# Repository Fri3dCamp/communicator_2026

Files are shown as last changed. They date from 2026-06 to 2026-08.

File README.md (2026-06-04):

# Communicator 2026
In deze Git repository kan je de ontwerpbestanden en productiedata vinden van de [Fri3d Camp](https://fri3d.be/) 2026 communcator add-on. Revisie 01 is de versie die je in de zakjes kan terugvinden.

De PCB bevat volgende elementen:

- [WCH CH32X035](https://www.wch-ic.com/products/CH32X035.html) microcontroller voor het keyboard
- [I²S Microfoon](datasheets/MIC.pdf)
- [I²S DAC met versterker](datasheets/AMP.pdf)

In de zak zal je ook nog volgende items aantreffen:

- [Luidspreker](Datasheets/SPK.pdf)
- 2 lange pin headers
- Cover PCB
- 4 lange plastieken spacers
- 4 korte plastieken spacers

Je zal zelf de speaker en pin headers nog moeten solderen, het siliconen keyboard op de PCB monteren met de afdekplaat en het op de badge klikken.

Het keyboard werkt ook als USB keyboard.

[//]: # (Communicator 2026)

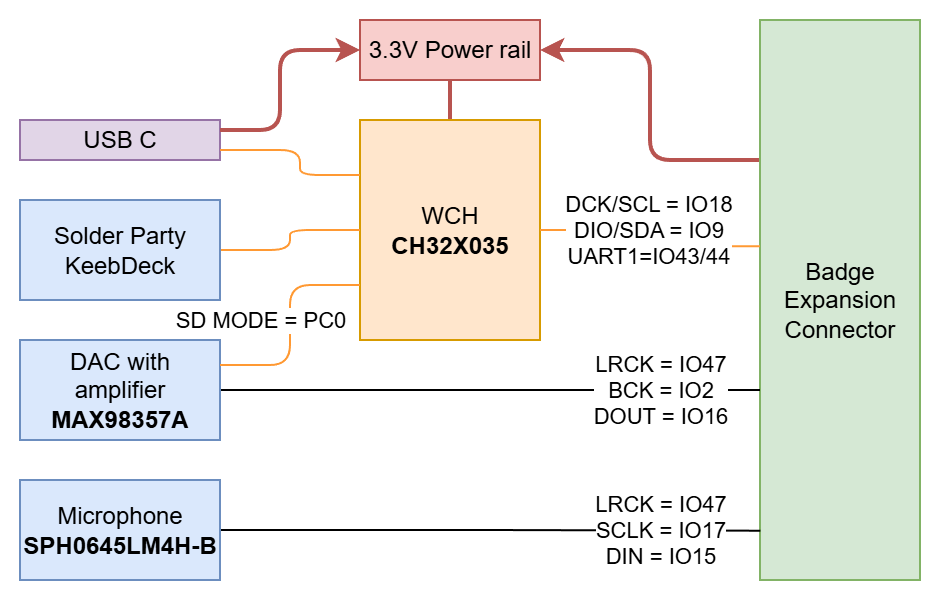
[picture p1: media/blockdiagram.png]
Communicator 2026 blockdiagram


# Communicator 2026 (EN)
Communicator addon for the Fri3d Badge based on the [Solder Party KeebDeck Keyboard](https://www.solder.party/keeb/). The design is very similar to the [previous generation](https://github.com/Fri3dCamp/communicator_2024) but we ditched the [LANA TNY](https://phyx.be/LANA_TNY/) module in favor of the [WCH CH32X035](https://www.wch-ic.com/products/CH32X035.html) microcontroller.

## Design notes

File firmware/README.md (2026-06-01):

## Fri3d Camp 2026 Communicator add-on firmware

This firmware runs on the Fri3d camp 2026 communicator add-on board, which is powered by [CH32X035](https://www.wch-ic.com/products/CH32X035.html) MCU, the same part that can be found as a coprocessor on the Fri3d badge 2026. More information about the 2026 communicator addon can be found [here](https://fri3dcamp.github.io/badge_2026/en/communicator/) ([dutch](https://fri3dcamp.github.io/badge_2026/communicator)). This MCU only controls the keyboard part of the communicator. The audio related functions of the communicator are handled by the main MCU of Fri3d badge through the expansion connector.

The firmware outputs [HID report packets](https://files.microscan.com/helpfiles/ms4_help_file/ms-4_help-02-46.html) (8 bytes) on USB and UART on the expansion connector. So the 2026 communicator addon can be used standalone using the USB connector attached to a PC for use as a normal keyboard, or in combination with the Fri3d badge [2024](https://github.com/Fri3dCamp/badge_2024) or [2026](https://github.com/Fri3dCamp/badge_2026) using the expansion connector.

## HID Report packets

A HID report packet ([Protocol 1](https://www.usb.org/sites/default/files/hid1_11.pdf)) consists of 8 bytes. The first byte indicates the modifier keys that have been pressed:

| Bit | Modifier Key |
|-|-|
| 7 | RIGHT GUI |
| 6 | RIGHT ALT |
| 5 | RIGHT SHIFT |
| 4 | RIGHT CTRL |
| 3 | LEFT GUI |
| 2 | LEFT ALT |
| 1 | LEFT SHIFT |
| 0 | LEFT CTRL |

The second byte is reserved, the remaining 6 bytes can contain a [HID keycode](https://gist.github.com/MightyPork/6da26e382a7ad91b5496ee55fdc73db2).

On the 2026 communicator, UART RX is also connected to the expansion connector. This means the badge firmware can send a byte to control the backlight of the 2026 communicator. The byte should set a value between 0 and 100.

### I2C

The Fri3d badge [2024](https://github.com/Fri3dCamp/badge_2024) and [2026](https://github.com/Fri3dCamp/badge_2026) can also communicate with the 2026 communicator add-on through I2C (address ```0x40```). The following registers can be used to interface/control with the add-on:

| Register | Name | Access | Bytes | description |
|-|-|-|-|-|
| 0x00 | Version number | R | 3 | Reports the firmware version number |
| 0x03 | current HID report packet | R | 8 | An 8-byte HID report packet (see above) |
| 0x0b | Configuration | R/W | 1 | a 1-byte configuration register (see below) |
| 0x0c | Backlight | R/W | 2 | Keyboard backlight intensity (0-100) |

The configuration is a 1-byte value with the following encoding:
| Bit | Name |
|-|-|
| \[7:2\] | reserved |
| 1 | reboot to bootloader |
| 0 | enable interrupt mode (not implemented yet) |

## Building

Use [platformio](https://platformio.org) to build this project. You should install the [ch32v platform package](https://github.com/Community-PIO-CH32V/platform-ch32v) as well. If you use the command line, build using:

```
pio run
```

## Flashing

### Through USB

To flash your device, unplug the USB cable, press and hold the boot button on the board while plugging in the USB cable again. Then upload using the command:

```
pio run -t upload
```

It will use [wchisp](https://github.com/Community-PIO-CH32V/tool-wchisp) to flash the binary to the [CH32X035](https://www.wch-ic.com/products/CH32X035.html) chip.

### Using your badge

Unlike the 2024 communicator, the 2026 communicator can be reflashed by your badge.
TODO: link to flashing instructions (micropython app?)

## Usage

The keyboard presents itself as a HID input device.
The ```Fn``` key can be used to trigger special functions:
 * ```Fn+Backspace```: Delete
 * ```Fn+Up```: Page Up
 * ```Fn+Down```: Page Down
 * ```Fn+Left```: Home
 * ```Fn+Right```: End
 * ```Fn+Spacebar```: Toggle keyboard backlight
 * ```Fn+Right Shift```: Toggle Caps Lock

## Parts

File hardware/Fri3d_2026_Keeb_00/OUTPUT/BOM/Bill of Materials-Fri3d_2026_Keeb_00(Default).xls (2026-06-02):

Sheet: BOM Report
Bill of Materials |  |  | Fri3D 2026 Keeb
Project: |  | Fri3d_2026_Keeb_00.PrjPcb
Revision: |  | 00
Variant: |  | Default
Creation Date: | 01/03/2026 | 23:25
Print Date: | 2026-03-18 | 19:16:56
Footprint | Comment | LibRef | Designator | Value | Description | Supplier 1 | Supplier Part Number 1 | Supplier 2 | Supplier Part Number 2 | Supplier 3 | Supplier Part Number 3 | Quantity
C0805_N |  | CAP # 10uF 10V 0805 | C1 | 10uF 10V | CAP # 10uF 10V 0805 | Farnell | 2320859 | LCSC | C17024 | Generic | 10uF 10V 0805 X7R | 1
C0603_N |  | CAP # 100nF 16V 0603 | C2, C8, C9 | 100nF 16V | CAP # 100nF 16V 0603 | LCSC | C282519 |  |  | Generic | 100nF 16V 0603 X7R | 3
C0603_N |  | CAP # 220pF 50V 0603 | C3, C4 | 220pF | CAP # 220pF 50V 0603 | LCSC | C5254623 | LCSC | C107081 | Generic | 220pF 0603 | 2
C0603_N |  | CAP # 1uF 50V 0603 | C5, C6 | 1uF 50V | CAP # 1uF 50V 0603 | Farnell | 2112858 |  |  | Generic | 1uF 50V 0603 X7R | 2
LITE_LTW-010DCG | Side emitting Cool White LED 3.0V 30mA 120° 2900mcd | LED # White Side Emitting LTW-010DCG-SR-G | D1, D2, D3, D4, D5, D6, D7, D8 | LTW-010DCG-SR-G | LED # White Side Emitting LTW-010DCG-SR-G | LCSC | C5175311 | LCSC | C5175309 | LCSC | C5175310 | 8
SOD-323_AC | CUS10S30 Schottky Power Rectifier, 1A, 30V | Schottky # CUS10S30 | D9 | CUS10S30,H3F | Schottky # CUS10S30 | LCSC | C146335 |  |  |  |  | 1
L0603 | BLM18KG601SN1D | FER # 600R 1A3 0603 0R15 BLM18KG601SN1D | F1, F2 | 1A3 0R15 | FER # 600R 1A3 0603 0R15 BLM18KG601SN1D | Farnell | 1781094 | LCSC | C85833 |  |  | 2
XUNPU-TYPEC-304S-ACP16 | USB 2.0 C Reversible Receptacle Horizontal full SMD | USB # C 2.0 RCPT TYPEC-304S-ACP16 | J1 | TYPEC-304S-ACP16 | USB # C 2.0 RCPT TYPEC-304S-ACP16 | LCSC | C5187472 | LCSC | C2927040 | LCSC | C5156603 | 1
HDR2X6 | Header 6X2 | Pin Header 2.54mm dual row 12way | P1 |  | Pin Header 2.54mm dual row 12way |  |  |  |  |  |  | 1
R0603_N |  | RES # 100R 0603 | R1, R5, R12, R13, R14, R15, R16, R17 | 100R | RES # 100R 0603 | Farnell | 2446544 | LCSC | C22775 | Generic | 100R 1% 0603 | 8
R0603_N |  | RES # 100K 0603 | R3, R6, R7, R18 | 100K | RES # 100K 0603 | LCSC | C25803 | LCSC | C14675 | Generic | 100K 1% 0603 | 4
R0603_N |  | RES # 1M 0603 | R4 | 1M | RES # 1M 0603 | LCSC | C22935 | LCSC | C105578 | Generic | 1M 1% 0603 | 1
R0603_N |  | RES # 5K1 0603 | R10, R11 | 5K1 | RES # 5K1 0603 | Farnell | 2845922 | LCSC | C112314 | Generic | 5K1 1% 0603 | 2
 | INGHAi GSPK3020035PN 8R 1W 100mm Leads | SPEAKER 8R 1W 10cm | SPK1 | GSPK3020035PN-8R1.0W-L100 | SPEAKER 8R 1W 10cm | LCSC | C530556 |  |  |  |  | 1
Solder_Party_Keyb | Full QWERTY Keyboard Solder Party Dome Sheet | Solder_Party_Keyb | SW1 |  |  |  |  |  |  |  |  | 1
WE_430181038816 | 4.5x4.5mm tact SMD H3,8mm | SW # TACT small 4.5x4.5mm SMD WS-TASV | SW2 | 430181038816 | SW # TACT small 4.5x4.5mm SMD WS-TASV | Wurth | 430181038816 | Mouser | 710-430181038816 | LCSC | C174049 | 1
SOT23-3 | 0.2A N-Ch MOSFET Vgs 1.5 | BSS138 N-Ch MOSFET 0.2A 1.5Vgs 60Vds | T1 | BSS138 | BSS138 N-Ch MOSFET 0.2A 1.5Vgs 60Vds | Farnell | 2432717 | LCSC | C426569 | LCSC | C5224260 / C5224267 | 1
QFN_16_0.5_3X3 | Mono I²S DAC AMP 3W 2.5~5.5V | AMP # AUD MAX98357A | U1 | MAX98357A | AMP # AUD MAX98357A | Farnell | 2949165 | LCSC | C910544 |  |  | 1
SOT23-5 | 3V3 LDO 300mA 150mV | LDO # 3V3 300mA RT9078-33GJ5 | U2 | RT9078-33GJ5 | LDO # 3V3 300mA RT9078-33GJ5 | LCSC | C110427 |  |  |  |  | 1
TDK_ICS-43434 | I2S MIC ICS-43434 | MIC # MEMS I2S ICS-43434 | U5 | ICS-43434 | MIC # MEMS I2S ICS-43434 | Mouser | 410-ICS-43434 | Farnell | 2911502 |  |  | 1
QFN_28_4.0x4.0_P0.4 | WCH CH32X035G8U6 QFN28 RISC-V 32-bit MCU, 62KB Flash, 10KB RAM, USB PD | RISCV # CH32X035G8U6 | U6 | CH32X035G8U6 | RISCV # CH32X035G8U6 | LCSC | C7437027 |  |  |  |  | 1
 |  |  |  |  |  |  |  |  |  |  |  | 44
Approved |  | Notes

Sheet: Print
Footprint | Designator | Description | Quantity
C0805_N | C1 | CAP # 10uF 10V 0805 | 1
C0603_N | C2, C8, C9 | CAP # 100nF 16V 0603 | 3
C0603_N | C3, C4 | CAP # 220pF 50V 0603 | 2
C0603_N | C5, C6 | CAP # 1uF 50V 0603 | 2
LITE_LTW-010DCG | D1, D2, D3, D4, D5, D6, D7, D8 | LED # White Side Emitting LTW-010DCG-SR-G | 8
SOD-323_AC | D9 | Schottky # CUS10S30 | 1
L0603 | F1, F2 | FER # 600R 1A3 0603 0R15 BLM18KG601SN1D | 2
XUNPU-TYPEC-304S-ACP16 | J1 | USB # C 2.0 RCPT TYPEC-304S-ACP16 | 1
HDR2X6 | P1 | Pin Header 2.54mm dual row 12way | 1
R0603_N | R1, R5, R12, R13, R14, R15, R16, R17 | RES # 100R 0603 | 8
R0603_N | R3, R6, R7, R18 | RES # 100K 0603 | 4
R0603_N | R4 | RES # 1M 0603 | 1
R0603_N | R10, R11 | RES # 5K1 0603 | 2
Solder_Party_Keyb | SW1 |  | 1
WE_430181038816 | SW2 | SW # TACT small 4.5x4.5mm SMD WS-TASV | 1
SOT23-3 | T1 | BSS138 N-Ch MOSFET 0.2A 1.5Vgs 60Vds | 1
QFN_16_0.5_3X3 | U1 | AMP # AUD MAX98357A | 1
SOT23-5 | U2 | LDO # 3V3 300mA RT9078-33GJ5 | 1
TDK_ICS-43434 | U5 | MIC # MEMS I2S ICS-43434 | 1
QFN_28_4.0x4.0_P0.4 | U6 | RISCV # CH32X035G8U6 | 1
 |  |  | 43
Approved

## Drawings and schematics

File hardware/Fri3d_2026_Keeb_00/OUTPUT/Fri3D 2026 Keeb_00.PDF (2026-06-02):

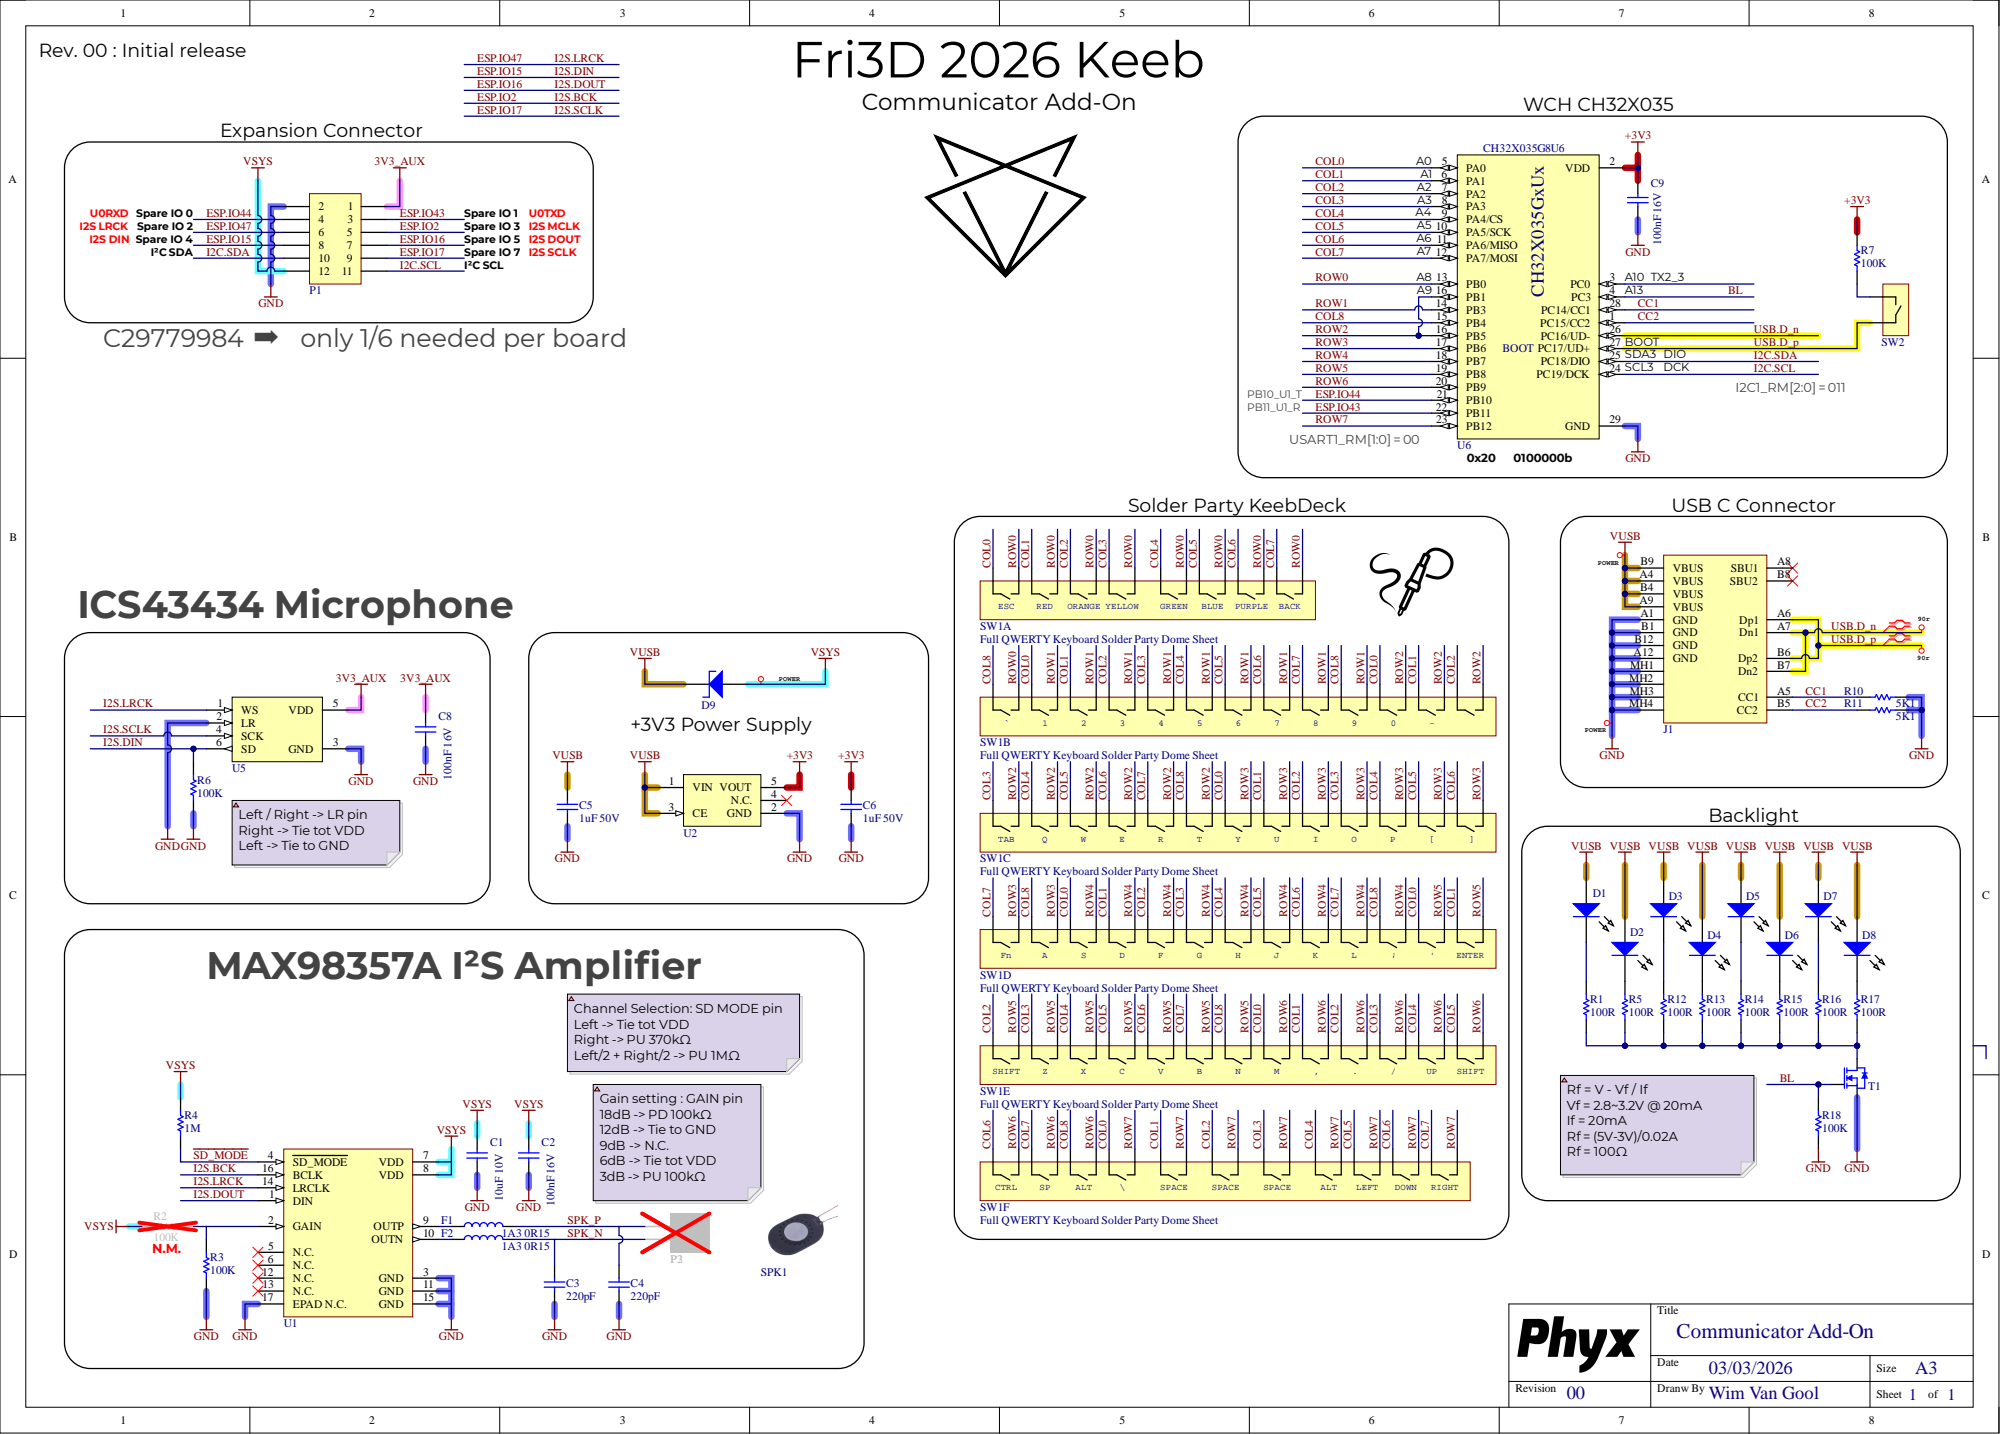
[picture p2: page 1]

Fri3D 2026 Keeb Rev. 00 : Initial release

C29779984 ➡ only 1/6 needed per board

Full QWERTY Keyboard Solder Party Dome Sheet

GND A12
MH1

MH2
MH3

Left / Right -> LR pin
Right -> Tie tot VDD
Left -> Tie to GND

VUSB VUSB VUSB VUSB VUSB VUSB VUSB

Channel Selection: SD MODE pin
Left -> Tie tot VDD
Right -> PU 370kΩ
Left/2 + Right/2 -> PU 1MΩ

Gain setting : GAIN pin
12dB -> Tie to GND

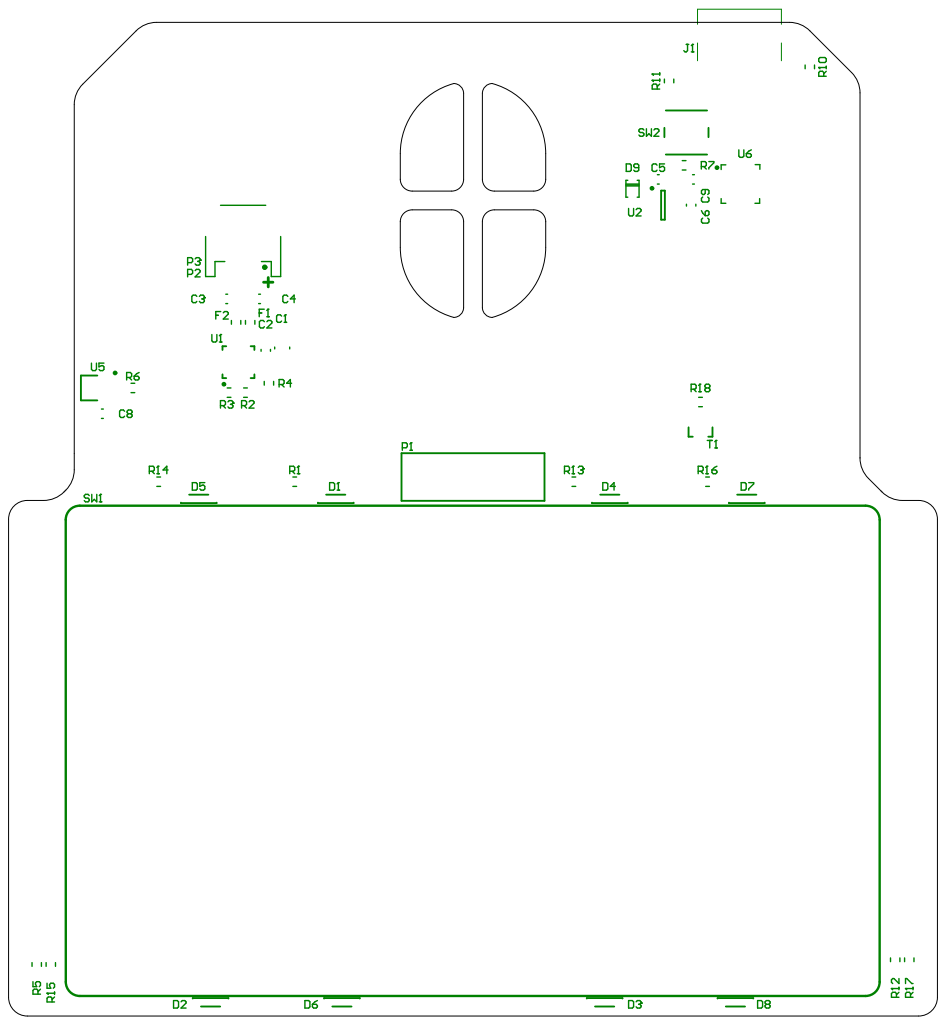
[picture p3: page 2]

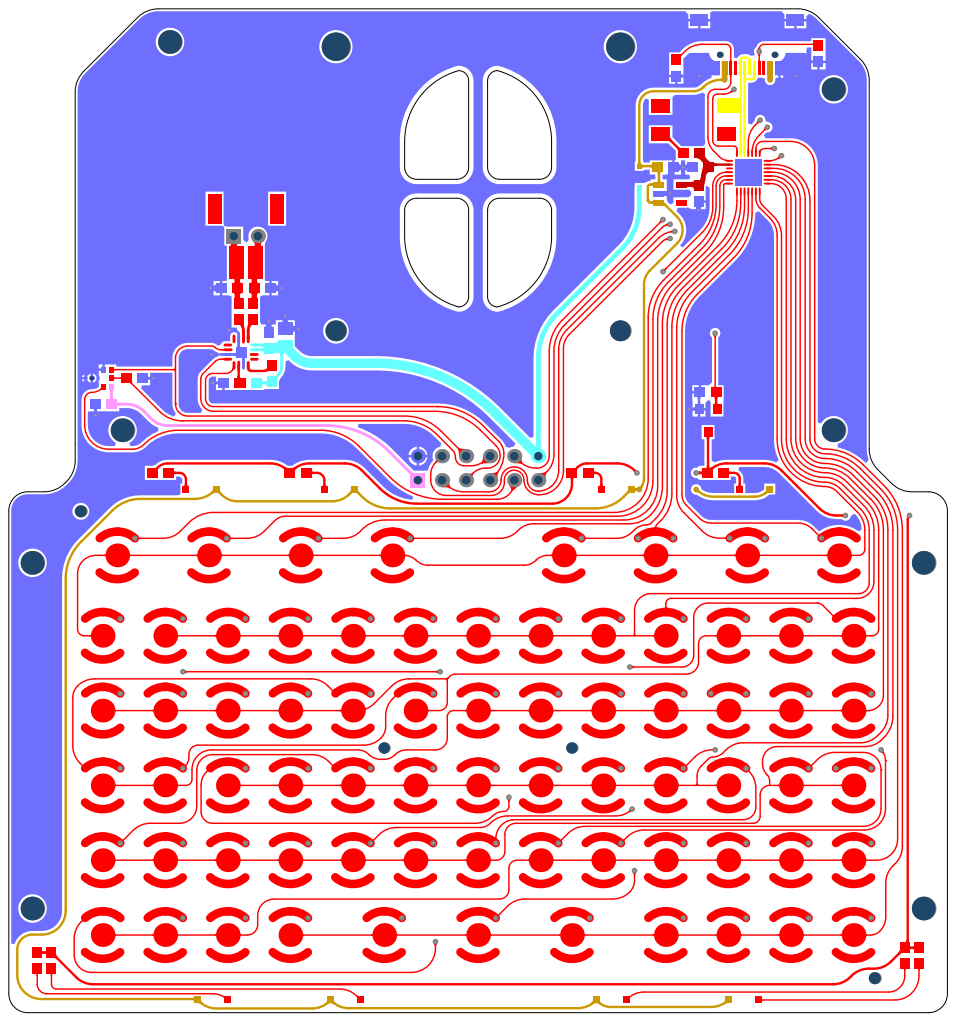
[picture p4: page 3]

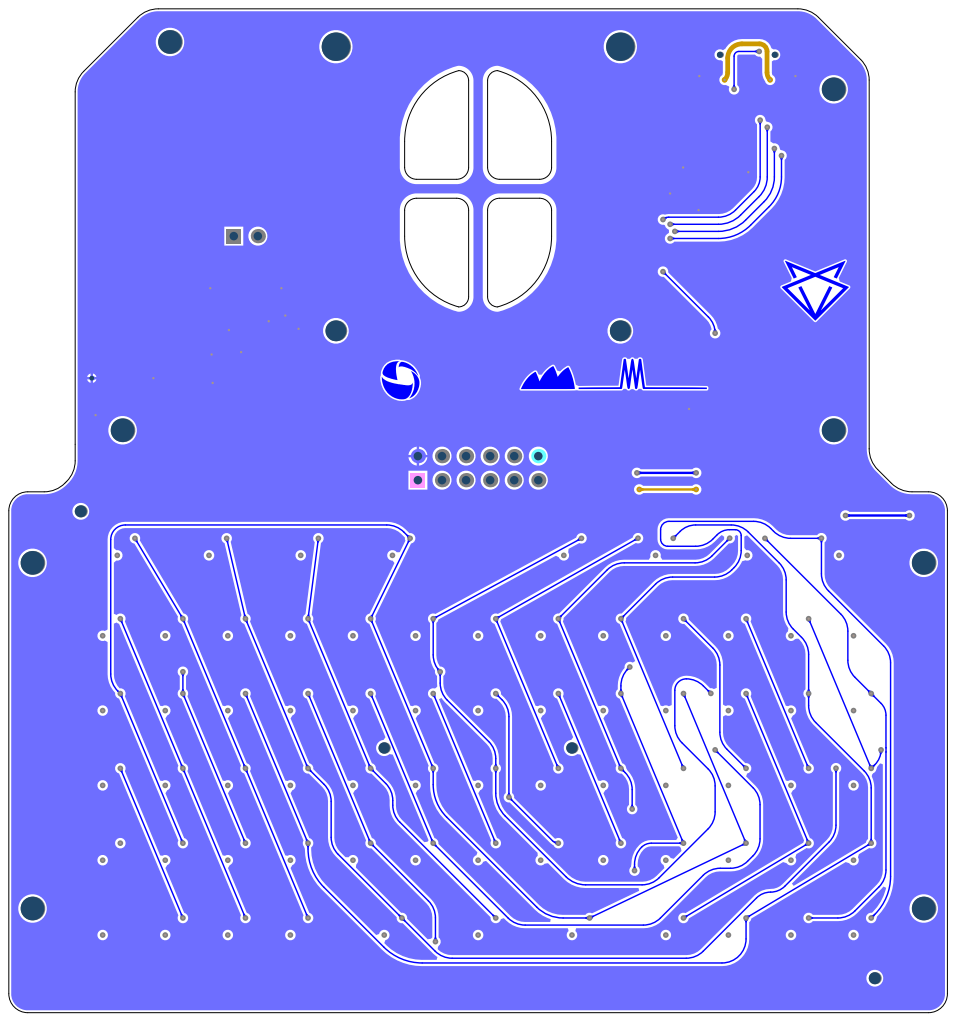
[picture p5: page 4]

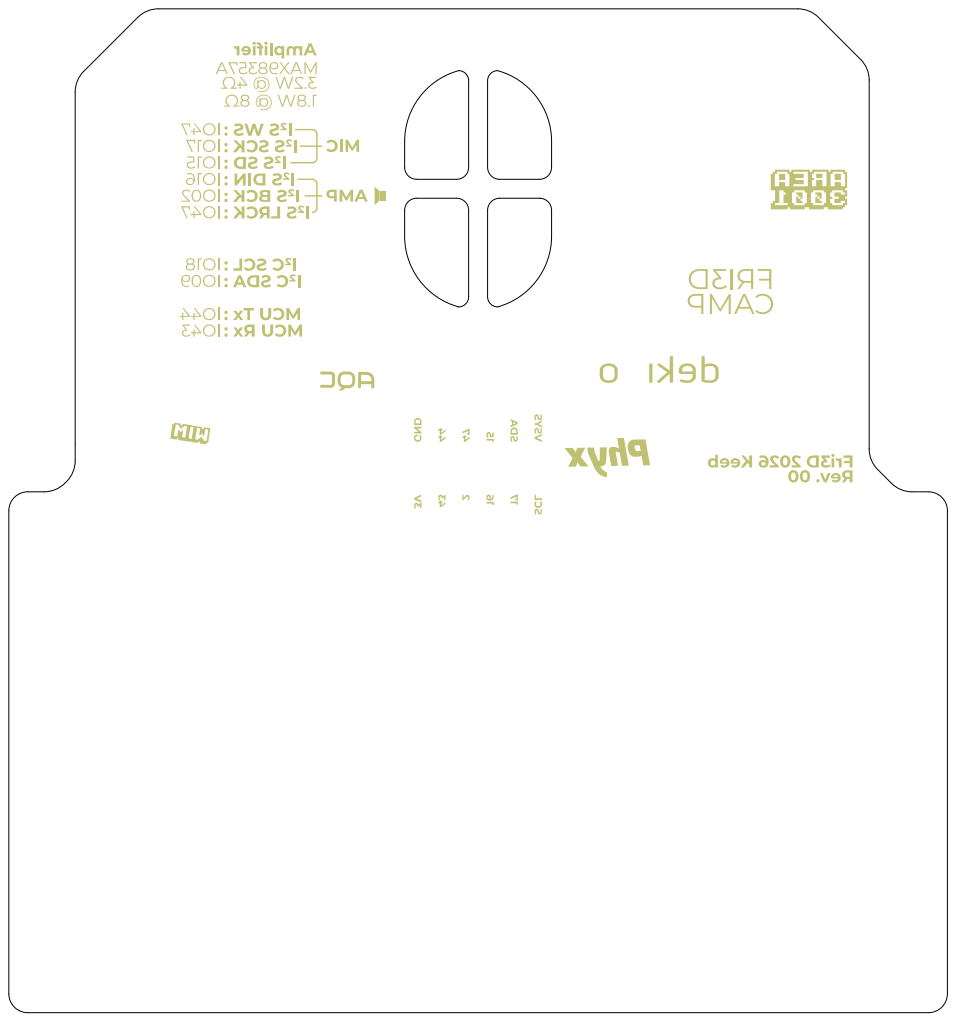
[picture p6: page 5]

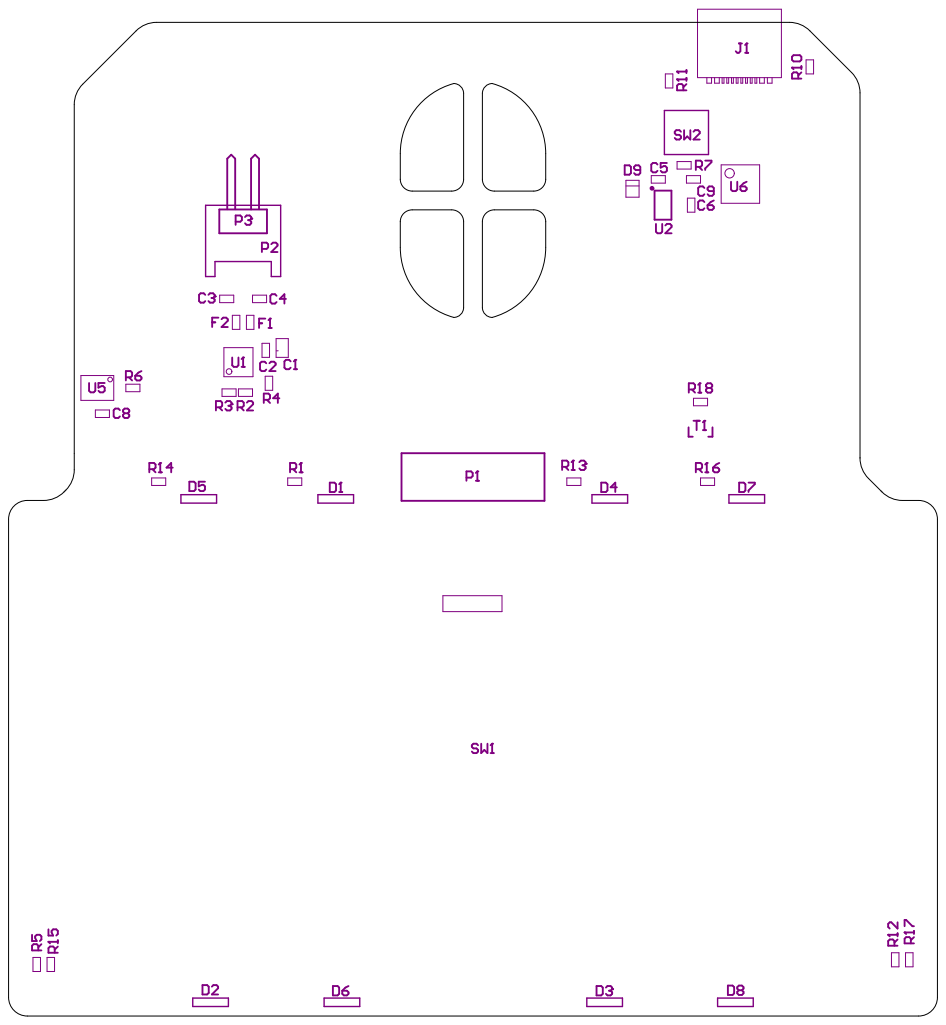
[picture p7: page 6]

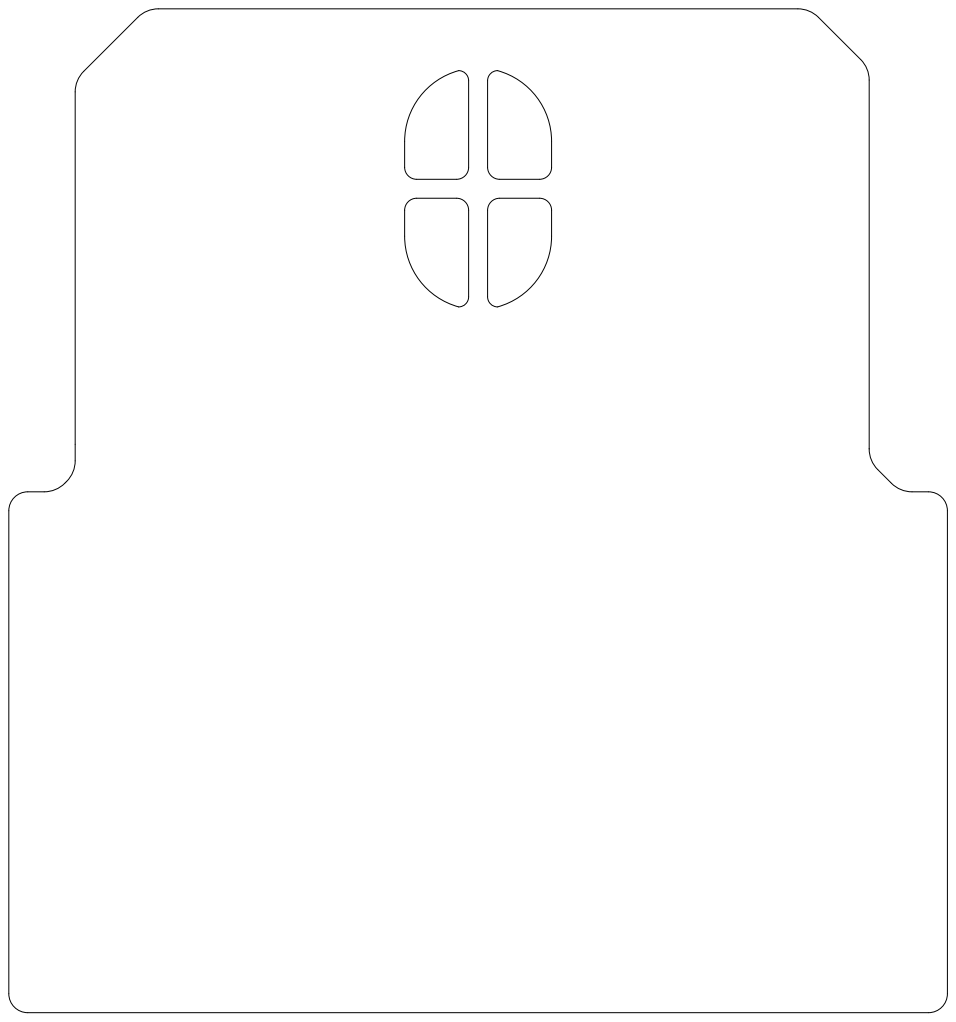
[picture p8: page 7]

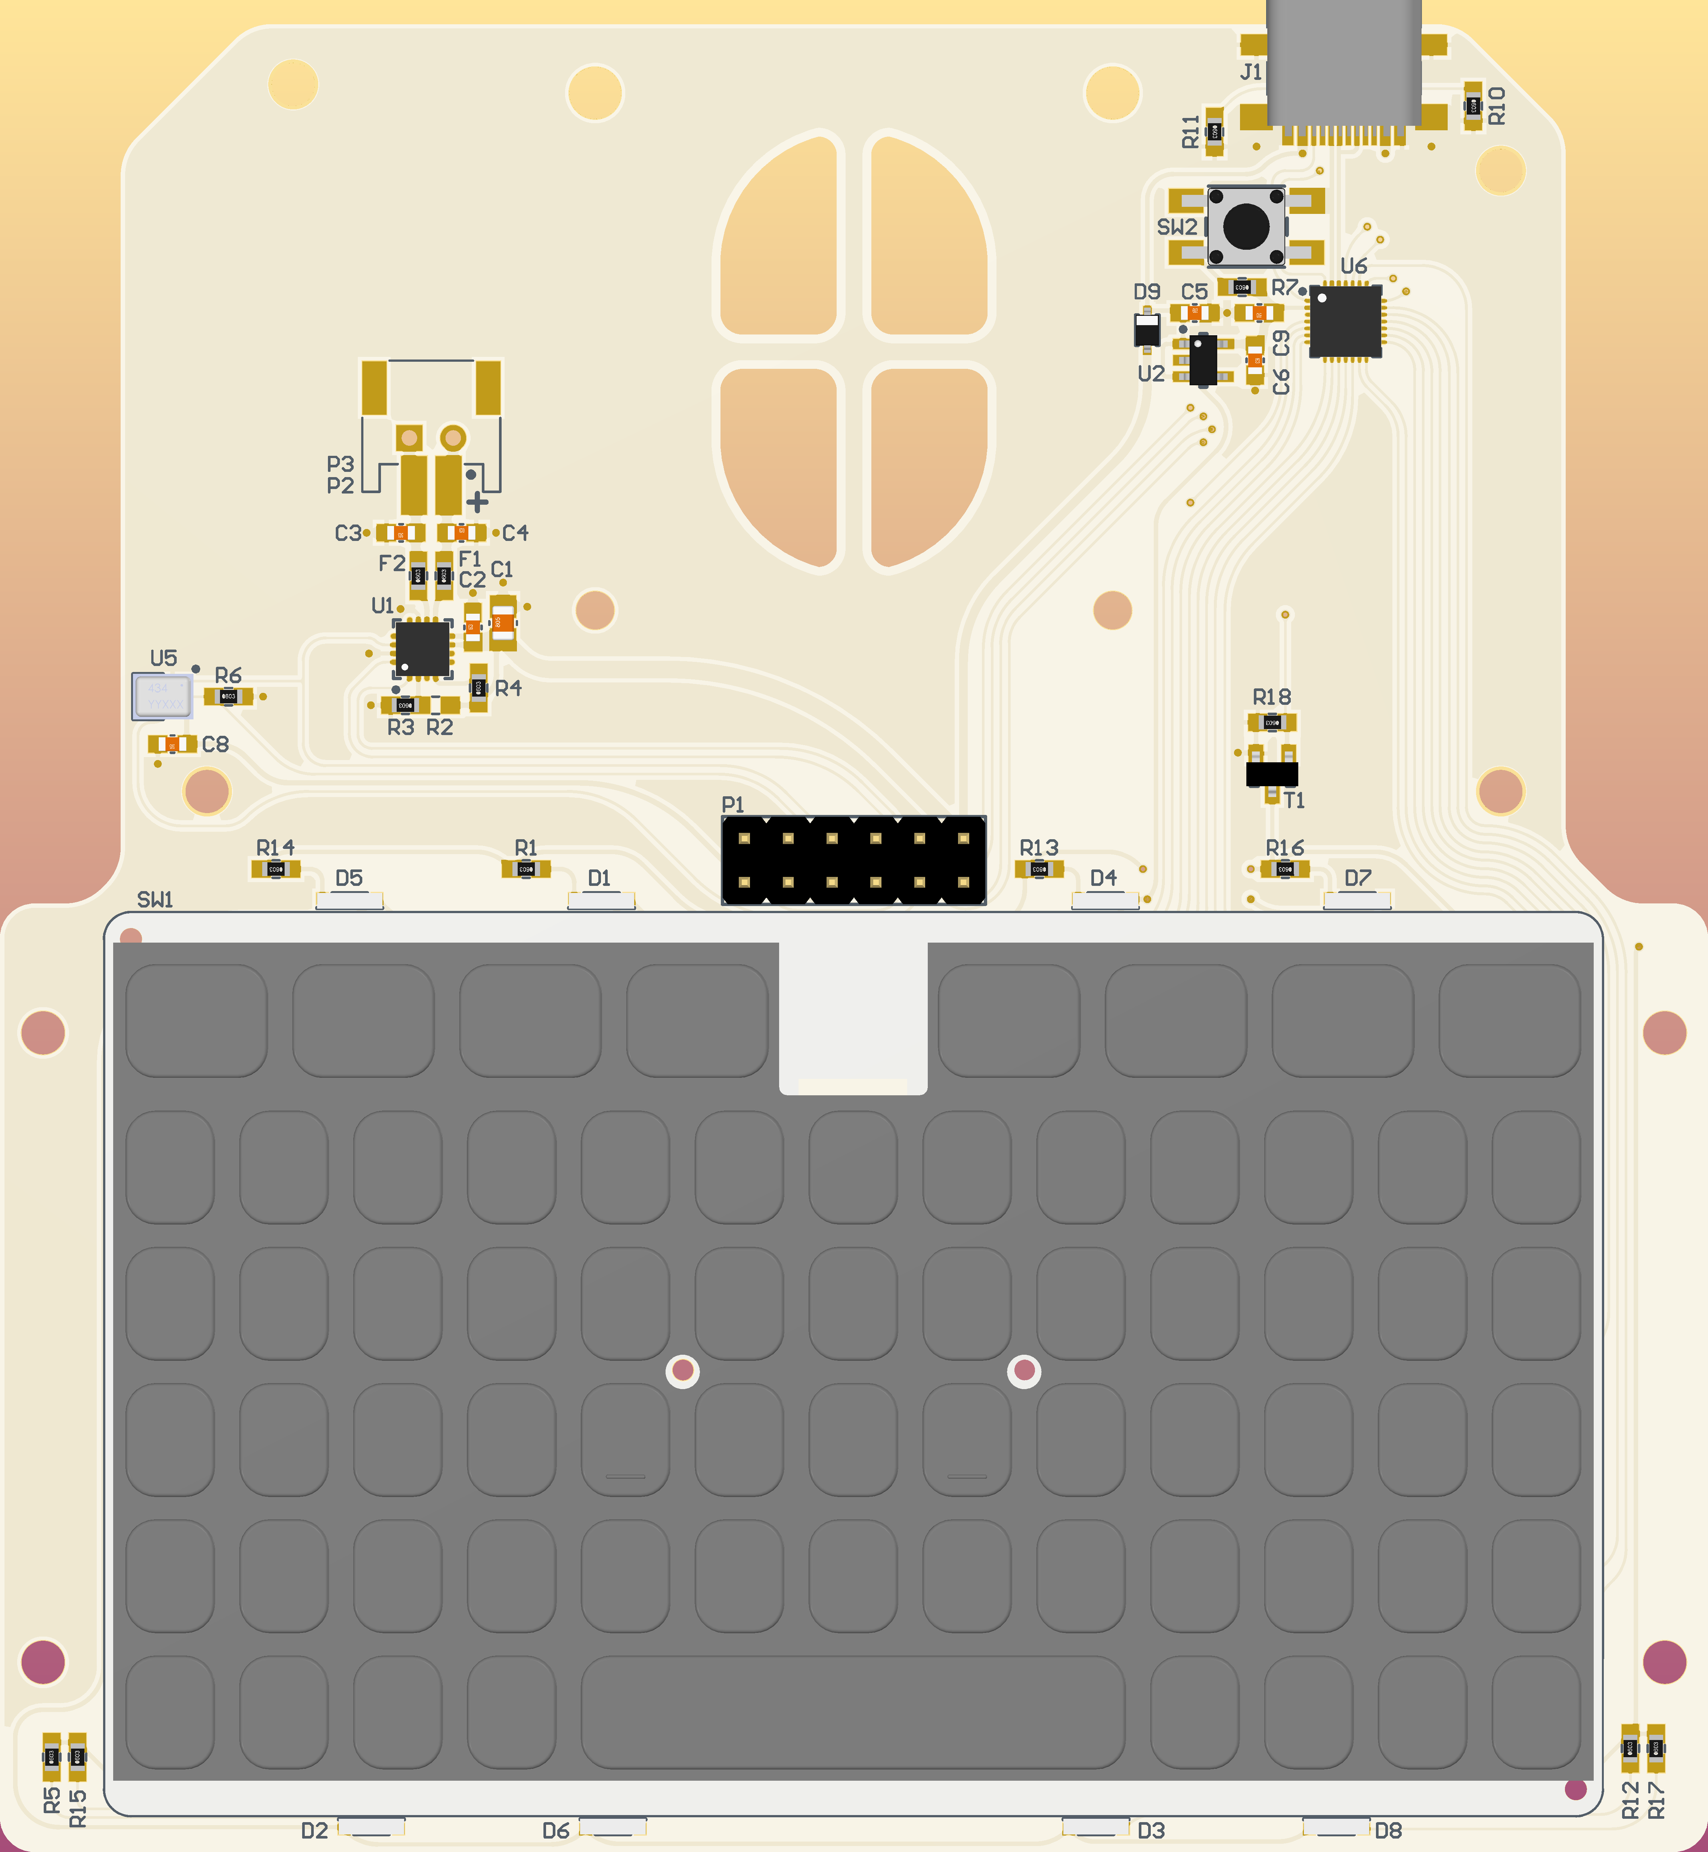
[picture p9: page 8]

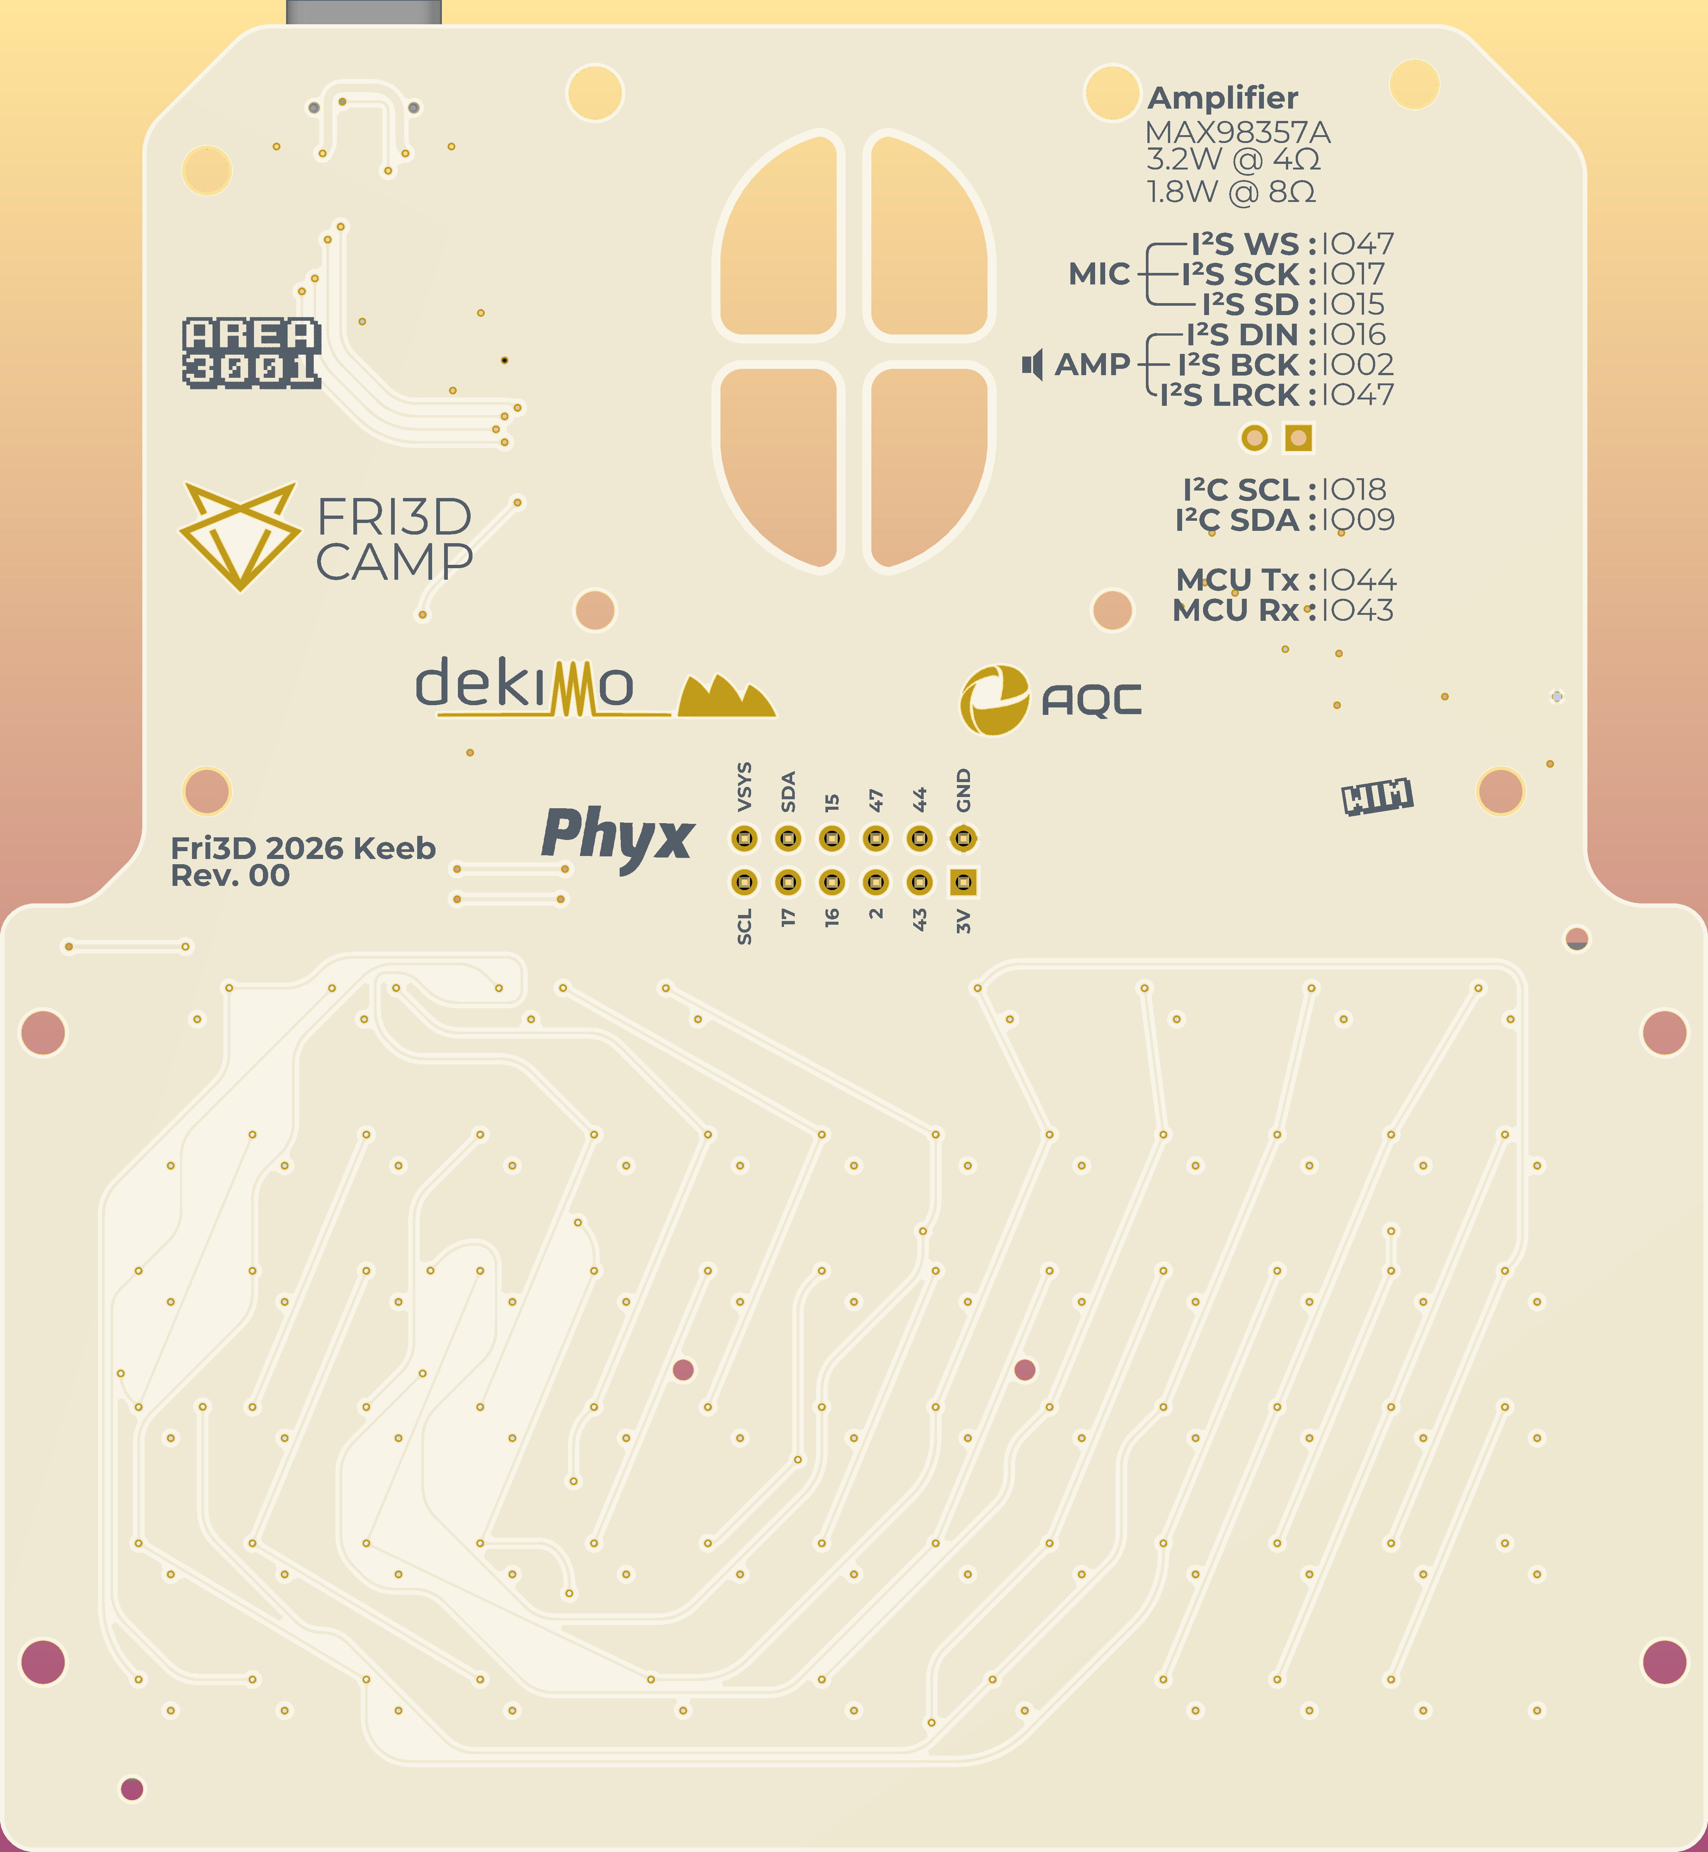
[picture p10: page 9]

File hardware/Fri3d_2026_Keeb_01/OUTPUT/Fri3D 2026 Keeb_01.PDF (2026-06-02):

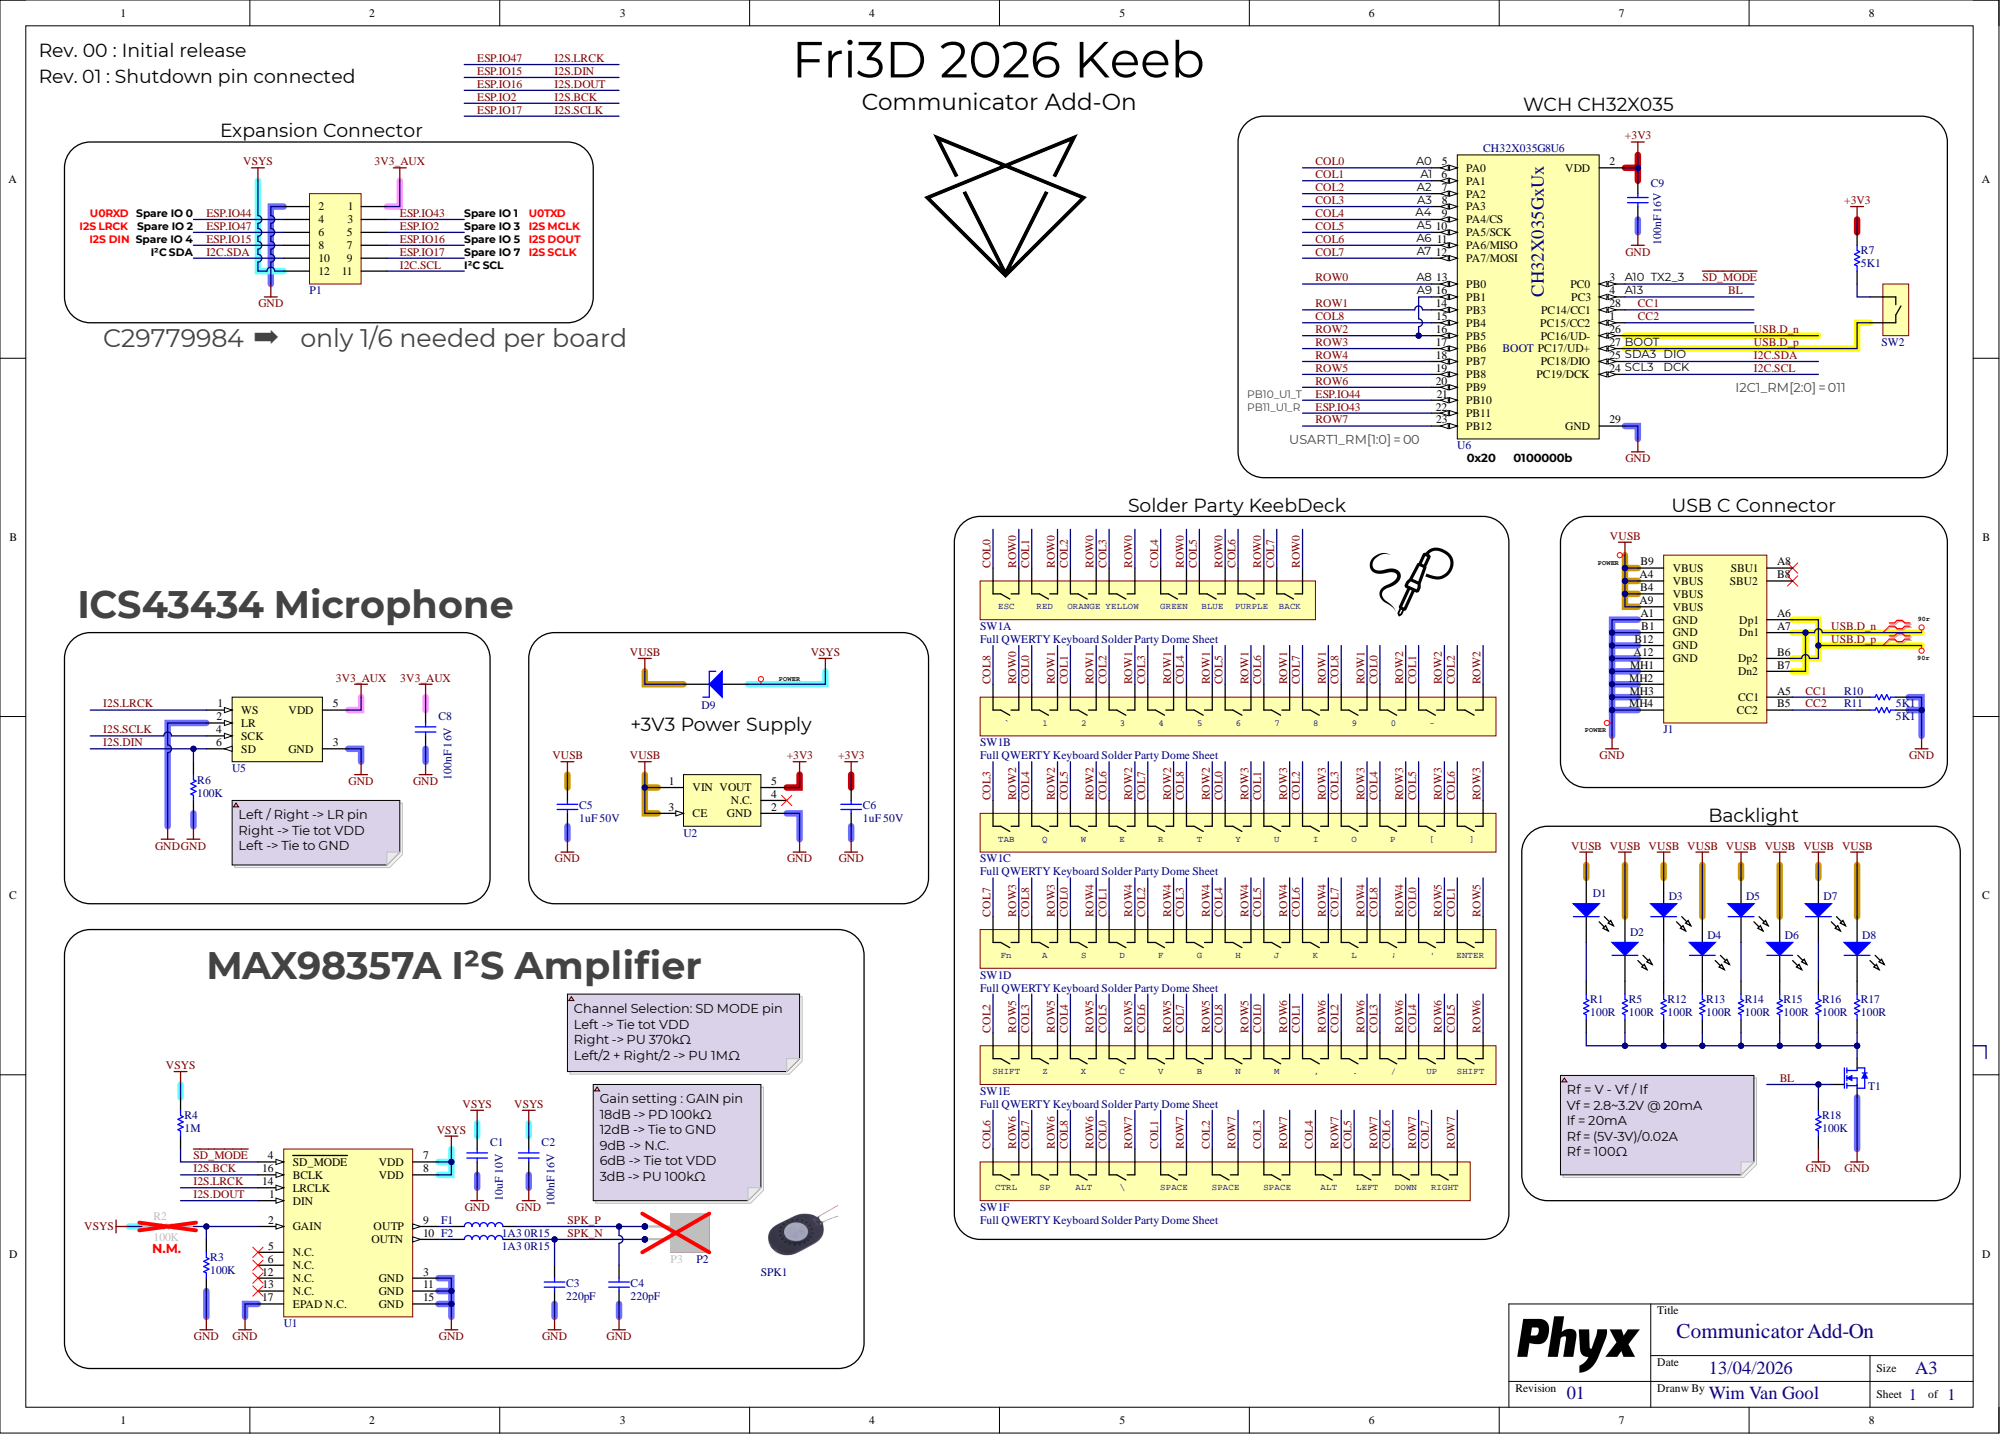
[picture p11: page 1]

Fri3D 2026 Keeb Rev. 00 : Initial release
Rev. 01 : Shutdown pin connected

C29779984 ➡ only 1/6 needed per board

Full QWERTY Keyboard Solder Party Dome Sheet

GND A12
MH1

MH2
MH3

Left / Right -> LR pin
Right -> Tie tot VDD
Left -> Tie to GND

VUSB VUSB VUSB VUSB VUSB VUSB VUSB

Channel Selection: SD MODE pin
Left -> Tie tot VDD
Right -> PU 370kΩ
Left/2 + Right/2 -> PU 1MΩ

Gain setting : GAIN pin
12dB -> Tie to GND

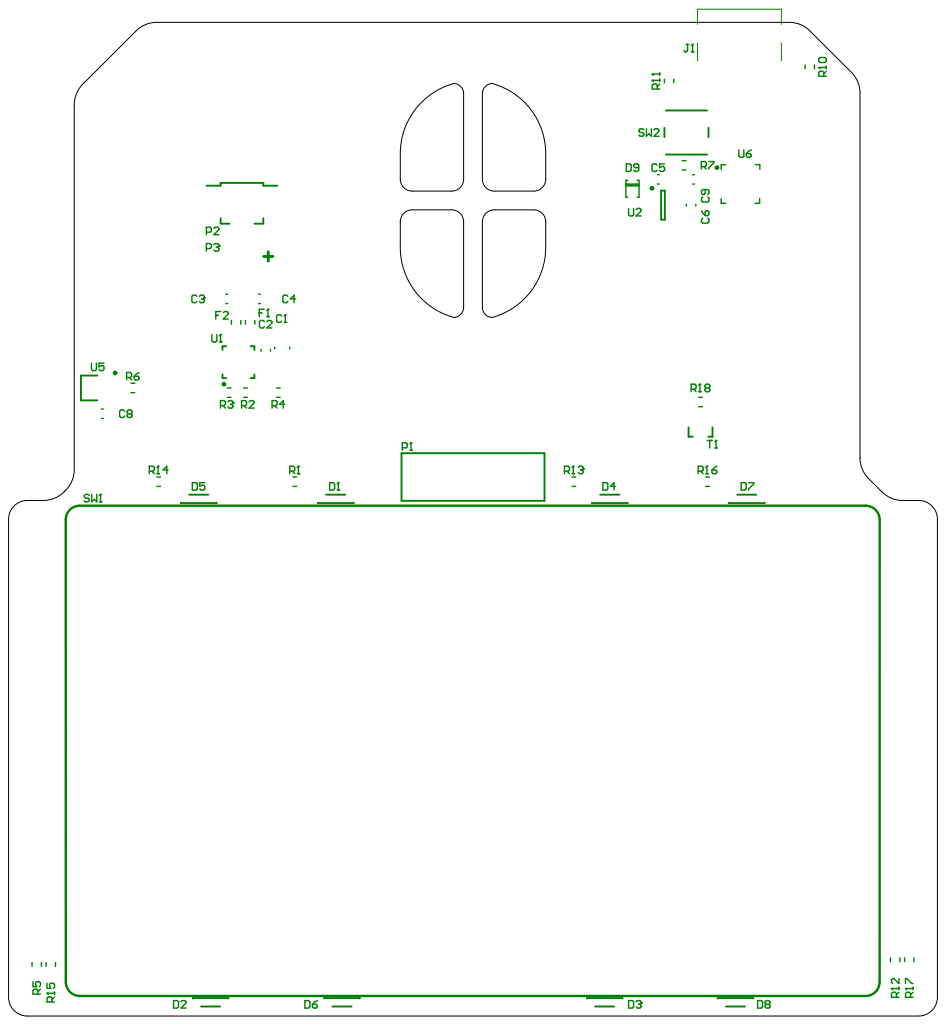
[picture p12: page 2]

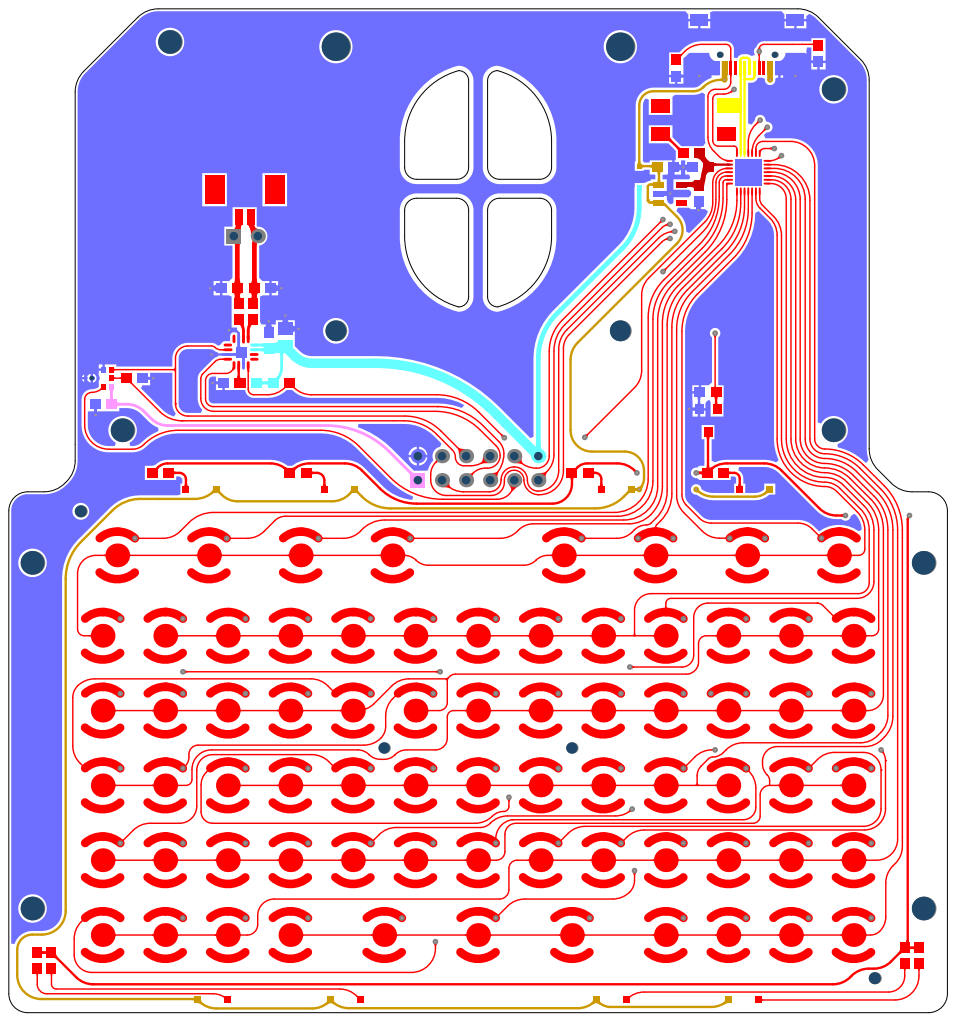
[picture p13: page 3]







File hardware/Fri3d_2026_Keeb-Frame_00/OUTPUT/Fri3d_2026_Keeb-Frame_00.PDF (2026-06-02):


Fri3D 2026 Keep Cover Rev. 00 : Initial release
Rev. 01 : Production version







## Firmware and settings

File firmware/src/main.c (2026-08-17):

#include <ch32x035.h> /* both X033 and X035 */
#include <stdlib.h>   /* atoi() */
#include <string.h>   /* memset() */

#include <wch_usbhid_internal.h>

#include "keycodes.h"
/* we use our own custom debug lib
 * because the framework-wch-noneos-sdk does not allow disabling printf()
 */
#include "debug.h"

/* I2C on the expansion connector towards the badge */
#define SDA_PORT         GPIOC
#define SDA_PIN          GPIO_Pin_18
#define SCL_PORT         GPIOC
#define SCL_PIN          GPIO_Pin_19
#define I2C_ADDRESS      (0x39)
#define I2C_TIMEOUT      (-2)
#define I2C_SPEED        (400000)
#define UART_BAUDRATE    (115200)

/* digital outputs (button matrix) */
#define COL0_PORT GPIOA // PA0: col0
#define COL0_PIN  GPIO_Pin_0
#define COL1_PORT GPIOA // PA1: col1
#define COL1_PIN  GPIO_Pin_1
#define COL2_PORT GPIOA // PA2: col2
#define COL2_PIN  GPIO_Pin_2
#define COL3_PORT GPIOA // PA3: col3
#define COL3_PIN  GPIO_Pin_3
#define COL4_PORT GPIOA // PA4: col4
#define COL4_PIN  GPIO_Pin_4
#define COL5_PORT GPIOA // PA5: col5
#define COL5_PIN  GPIO_Pin_5
#define COL6_PORT GPIOA // PA6: col6
#define COL6_PIN  GPIO_Pin_6
#define COL7_PORT GPIOA // PA7: col7
#define COL7_PIN  GPIO_Pin_7
#define COL8_PORT GPIOB // PB4: col8
#define COL8_PIN  GPIO_Pin_4
#define N_COLS    (9)

#define ROW0_PORT GPIOB // PB0: row0
#define ROW0_PIN  GPIO_Pin_0
#define ROW1_PORT GPIOB // PB3: row1
#define ROW1_PIN  GPIO_Pin_3
#define ROW2_PORT GPIOB // PB5: row2 (TODO: PB1?)
#define ROW2_PIN  GPIO_Pin_5
#define ROW3_PORT GPIOB // PB6: row3
#define ROW3_PIN  GPIO_Pin_6
#define ROW4_PORT GPIOB // PB7: row4
#define ROW4_PIN  GPIO_Pin_7
#define ROW5_PORT GPIOB // PB8: row5
#define ROW5_PIN  GPIO_Pin_8
#define ROW6_PORT GPIOB // PB9: row6
#define ROW6_PIN  GPIO_Pin_9
#define ROW7_PORT GPIOB // PB12: row7
#define ROW7_PIN  GPIO_Pin_12
#define N_ROWS    (8) // fits perfectly in uint8_t

#define TIMER_FREQ ((SystemCoreClock / 10000) - 1) /* the output frequency of all timers: 100Hz */

/* backlight PWM */
#define BACKLIGHT_PORT            GPIOC // PC3: backlight LED
#define BACKLIGHT_PIN             GPIO_Pin_3
#define BACKLIGHT_TIM             TIM1                    // TIM1 Channel 4
#define BACKLIGHT_TIM_REMAP       GPIO_PartialRemap3_TIM1 // mapping 0b011
#define BACKLIGHT_TIM_CVR         TIM1->CH4CVR            // TIM1 Channel 4 compare register
#define BACKLIGHT_TIM_DMA_CHANNEL DMA1_Channel5           // DMA channel for TIM1_UP

/* UART */
#define UART_PORT   GPIOB
#define UART_TX_PIN GPIO_Pin_10 // PB10: UART TX
#define UART_RX_PIN GPIO_Pin_11 // PB11: UART RX
#define UART        USART1

/* 3 bytes: version number
 * 1 byte: button matrix state
 * 2 * ADC_CHANNELS bytes: 1 analog input is 16 bit
 * 1 byte: left encoder value
 * 1 byte: right encoder value
 * 3 * LEDS_NUM bytes: red, green, blue value for each LED
 * */
#define RESULT_BUFFER_SIZE      (3 + 8 + 1 + 2)
#define RESULT_KB_OFFSET        (3)
#define RESULT_CONFIG_OFFSET    (RESULT_KB_OFFSET + 8)
#define RESULT_BACKLIGHT_OFFSET (RESULT_CONFIG_OFFSET + 1)

#define HID_REPORT_KEYS (6)

typedef struct
{
    uint8_t modifiers;
    uint8_t reserved;
    uint8_t keys[HID_REPORT_KEYS];
} key_report_t;

/*
 * This struct contains all data that is available through I2C.
 * Use the following command with a Buspirate to test:
 * read version number : [ 0x72 0x00 [ 0x73 r:3 ]
 * read matrix state : [ 0x72 0x03 [ 0x73 r:1 ]
 * read analog inputs : [ 0x72 0x04 [ 0x73 r:16 ]
 * read buttons and analog inputs : [ 0x72 0x03 [ 0x73 r:17 ]
 * read left encoder : [ 0x72 0x14 [ 0x73 r:1 ]
 * read right encoder : [ 0x72 0x15 [ 0x73 r:1 ]
 * read both encoders : [ 0x72 0x14 [ 0x73 r:2 ]
 * turn on all leds : [ 0x72 0x16 0xFF:24 ]
 * turn off all leds : [ 0x72 0x16 0x00:24 ]
 * read everything : [ 0x72 0x00 [ 0x73 r:46 ]
 */
typedef struct __attribute__((packed))
{
    uint8_t version[3];      // version number
    key_report_t key_report; // reference to the button state byte in the result buffer
    uint8_t enable_int : 1;         // configuration flag to enable interrupt output instead of UART output (TODO)
    uint8_t reboot : 1;             // configuration flag to trigger a reboot to bootloader
    uint8_t remap : 1;              // write 1 to remap the SWD to the I2C pins
    uint8_t enable_uart_output : 1; // configuration flag to enable sending the HID report over UART; defaults to 1. When 0, UART is disabled and its pins are tri-stated
    uint8_t reserved : 4;           // reserved
    uint16_t backlight;      // backlight PWM value
} addon_data_t;

_Static_assert(sizeof(addon_data_t) == RESULT_BUFFER_SIZE, "raw data and struct size are not aligned!");

typedef struct
{
    uint8_t flag_matrix_scan_done : 1;    // flag to indicate that the button matrix state has changed
    uint8_t flag_int_should_clear : 1;    // flag to indicate that the interrupt should be cleared
    uint8_t flag_button_scan_halfway : 1; // flag to indicate that the matrix scan is halfway
    uint8_t flag_caps_lock : 1;           // reserved for future use
    uint8_t flag_config_changed : 1;      // flag to indicate that the configuration has changed through I2C
    uint8_t flag_slave_first_write : 1;   // set on every ADDR phase; the next RXNE byte is the register offset
    uint8_t flag_uart_enabled : 1;
    uint8_t reserved : 1;                 // reserved for future use
    uint8_t matrix_state[N_COLS];         // current matrix state
    uint8_t slave_offset;                 // register offset captured after the most recent ADDR+W
    uint8_t slave_position;              // current read/write cursor, reset to offset on every ADDR
    union
    {
        addon_data_t data;
        uint8_t raw_data[RESULT_BUFFER_SIZE];
    };
} addon_state_t;

/* Global Variables */
static addon_state_t state;

/* initialize timer 3 to periodically generate an interrupt */
static void TIM3_Init(uint16_t arr, uint16_t psc)
{
    TIM_TimeBaseInitTypeDef TIM_TimeBaseStructure = {0};
    NVIC_InitTypeDef NVIC_InitStructure = {0};

    /* Enable Timer3 Clock */
    RCC_APB1PeriphClockCmd(RCC_APB1Periph_TIM3, ENABLE);

    /* Initialize Timer3 */
    TIM_TimeBaseStructure.TIM_Period = arr;
    TIM_TimeBaseStructure.TIM_Prescaler = psc;
    TIM_TimeBaseStructure.TIM_ClockDivision = TIM_CKD_DIV1;
    TIM_TimeBaseStructure.TIM_CounterMode = TIM_CounterMode_Up;
    TIM_TimeBaseInit(TIM3, &TIM_TimeBaseStructure);

    /* enable timer interrupts */
    TIM_ITConfig(TIM3, TIM_IT_Update, ENABLE);

    /* configure timer interrupt */
    NVIC_InitStructure.NVIC_IRQChannel = TIM3_IRQn;
    NVIC_InitStructure.NVIC_IRQChannelPreemptionPriority = 1;
    NVIC_InitStructure.NVIC_IRQChannelSubPriority = 2;
    NVIC_InitStructure.NVIC_IRQChannelCmd = ENABLE;
    NVIC_Init(&NVIC_InitStructure);

    /* Enable Timer3 */
    TIM_Cmd(TIM3, ENABLE);
}

/* set a matrix column active */
static void KB_Set_Col(uint8_t col)
{
    switch (col)
    {
        case 0:
            GPIO_WriteBit(COL8_PORT, COL8_PIN, Bit_SET);
            GPIO_WriteBit(COL0_PORT, COL0_PIN, Bit_RESET);
            break;
        case 1:
            GPIO_WriteBit(COL0_PORT, COL0_PIN, Bit_SET);
            GPIO_WriteBit(COL1_PORT, COL1_PIN, Bit_RESET);
            break;
        case 2:
            GPIO_WriteBit(COL1_PORT, COL1_PIN, Bit_SET);
            GPIO_WriteBit(COL2_PORT, COL2_PIN, Bit_RESET);
            break;
        case 3:
            GPIO_WriteBit(COL2_PORT, COL2_PIN, Bit_SET);
            GPIO_WriteBit(COL3_PORT, COL3_PIN, Bit_RESET);
            break;
        case 4:
            GPIO_WriteBit(COL3_PORT, COL3_PIN, Bit_SET);
            GPIO_WriteBit(COL4_PORT, COL4_PIN, Bit_RESET);
            break;
        case 5:
            GPIO_WriteBit(COL4_PORT, COL4_PIN, Bit_SET);
            GPIO_WriteBit(COL5_PORT, COL5_PIN, Bit_RESET);
            break;
        case 6:
            GPIO_WriteBit(COL5_PORT, COL5_PIN, Bit_SET);
            GPIO_WriteBit(COL6_PORT, COL6_PIN, Bit_RESET);
            break;
        case 7:
            GPIO_WriteBit(COL6_PORT, COL6_PIN, Bit_SET);
            GPIO_WriteBit(COL7_PORT, COL7_PIN, Bit_RESET);
            break;
        case 8:
            GPIO_WriteBit(COL7_PORT, COL7_PIN, Bit_SET);
            GPIO_WriteBit(COL8_PORT, COL8_PIN, Bit_RESET);
            break;
        default:
            GPIO_WriteBit(GPIOA, COL0_PIN | COL1_PIN | COL2_PIN | COL3_PIN | COL4_PIN | COL5_PIN | COL6_PIN | COL7_PIN, Bit_SET);
            GPIO_WriteBit(COL8_PORT, COL8_PIN, Bit_SET);
    }
}

/* initialize the I2C interface */
static void IIC_Init(uint32_t bound, uint16_t address)
{
    GPIO_InitTypeDef GPIO_InitStructure = {0};
    I2C_InitTypeDef I2C_InitStructure = {0};
    NVIC_InitTypeDef NVIC_InitStruct = {0};

    /* enable I2C1 and GPIOC clocks */
    RCC_APB2PeriphClockCmd(RCC_APB2Periph_AFIO | RCC_APB2Periph_GPIOC, ENABLE);
    RCC_APB1PeriphClockCmd(RCC_APB1Periph_I2C1, ENABLE);

    /* remap PC18/PC19 to I2C1 SDA/SCL */
    GPIO_PinRemapConfig(GPIO_PartialRemap3_I2C1, ENABLE); // 011: Mapping (SCL/PC19, SDA/PC18)

    /* Disable DIO (SWD) interface on these pins */
    GPIO_PinRemapConfig(GPIO_Remap_SWJ_Disable, ENABLE);

    /* configure the GPIO as SDA/SCL pins */
    GPIO_InitStructure.GPIO_Pin = SDA_PIN | SCL_PIN;
    GPIO_InitStructure.GPIO_Mode = GPIO_Mode_AF_PP; // automatic open-drain
    GPIO_InitStructure.GPIO_Speed = GPIO_Speed_50MHz;
    GPIO_Init(GPIOC, &GPIO_InitStructure);

    /* configure I2C1 */
    I2C_InitStructure.I2C_ClockSpeed = bound;                                 // bus speed
    I2C_InitStructure.I2C_Mode = I2C_Mode_I2C;                                // there is only 1 mode
    I2C_InitStructure.I2C_DutyCycle = I2C_DutyCycle_16_9;                     // I2C fast mode Tlow/Thigh = 16/9
    I2C_InitStructure.I2C_OwnAddress1 = address << 1;                         // 7 or 10 bit address
    I2C_InitStructure.I2C_Ack = I2C_Ack_Enable;                               // automatic acknowledge
    I2C_InitStructure.I2C_AcknowledgedAddress = I2C_AcknowledgedAddress_7bit; // use 7 bit address
    I2C_Init(I2C1, &I2C_InitStructure);

    /* configure I2C interrupts */
    NVIC_InitStruct.NVIC_IRQChannel = I2C1_EV_IRQn;
    NVIC_InitStruct.NVIC_IRQChannelPreemptionPriority = 0;
    NVIC_InitStruct.NVIC_IRQChannelSubPriority = 1;
    NVIC_InitStruct.NVIC_IRQChannelCmd = ENABLE;
    NVIC_Init(&NVIC_InitStruct);

    NVIC_InitStruct.NVIC_IRQChannel = I2C1_ER_IRQn;
    NVIC_InitStruct.NVIC_IRQChannelPreemptionPriority = 0;
    NVIC_InitStruct.NVIC_IRQChannelSubPriority = 1;
    NVIC_InitStruct.NVIC_IRQChannelCmd = ENABLE;
    NVIC_Init(&NVIC_InitStruct);

    /* Enable I2C event, error, and buffer interrupts.
     * EVT fires on: address match, byte received, byte transmitted, stop detected.
     * ERR fires on: bus error, arbitration lost, acknowledge failure, etc.
     * BUF fires on: TXE/RXNE (needed so we get an interrupt for each data byte).
     */
    I2C_ITConfig(I2C1, I2C_IT_EVT | I2C_IT_ERR | I2C_IT_BUF, ENABLE);

    /* enable clock stretching */
    I2C_StretchClockCmd(I2C1, ENABLE);

    /* enable I2C1 */
    I2C_Cmd(I2C1, ENABLE);
}

// reference: https://github.com/openwch/ch32x035/blob/main/EVT/EXAM/TIM/TIM_DMA/User/main.c
static void Backlight_PWM_Init(uint16_t arr, uint16_t psc, uint16_t ccp)
{
    GPIO_InitTypeDef GPIO_InitStructure = {0};
    TIM_TimeBaseInitTypeDef TIM_TimeBaseInitStructure = {0};
    TIM_OCInitTypeDef TIM_OCInitStructure = {0};

    /* enable timers and GPIO clocks */
    RCC_APB2PeriphClockCmd(RCC_APB2Periph_AFIO | RCC_APB2Periph_TIM1 | RCC_APB2Periph_GPIOC, ENABLE);

    /* set pinmux */
    GPIO_PinRemapConfig(BACKLIGHT_TIM_REMAP, ENABLE); // set LCD backlight (PC3) on CH4 of TIM1

    GPIO_InitStructure.GPIO_Pin = BACKLIGHT_PIN;
    GPIO_InitStructure.GPIO_Mode = GPIO_Mode_AF_PP;
    GPIO_InitStructure.GPIO_Speed = GPIO_Speed_50MHz;
    GPIO_Init(BACKLIGHT_PORT, &GPIO_InitStructure);

    TIM_TimeBaseInitStructure.TIM_Period = arr;
    TIM_TimeBaseInitStructure.TIM_Prescaler = psc;
    TIM_TimeBaseInitStructure.TIM_ClockDivision = TIM_CKD_DIV1;
    TIM_TimeBaseInitStructure.TIM_CounterMode = TIM_CounterMode_Up;
    TIM_TimeBaseInitStructure.TIM_RepetitionCounter = 0;
    TIM_TimeBaseInit(BACKLIGHT_TIM, &TIM_TimeBaseInitStructure);

    TIM_OCInitStructure.TIM_OCMode = TIM_OCMode_PWM2; // High until CNT < CCR
    TIM_OCInitStructure.TIM_OutputState = TIM_OutputState_Enable;
    TIM_OCInitStructure.TIM_Pulse = ccp; // start duty cycle
    TIM_OCInitStructure.TIM_OCPolarity = TIM_OCPolarity_Low;
    TIM_OC4Init(BACKLIGHT_TIM, &TIM_OCInitStructure);

    TIM_OC4PreloadConfig(BACKLIGHT_TIM, TIM_OCPreload_Disable);
    TIM_ARRPreloadConfig(BACKLIGHT_TIM, ENABLE);
}

static void Backlight_PWM_DMA_Init(u32 memadr)
{
    DMA_InitTypeDef DMA_InitStructure = {0};

    RCC_AHBPeriphClockCmd(RCC_AHBPeriph_DMA1, ENABLE);

    DMA_DeInit(BACKLIGHT_TIM_DMA_CHANNEL);
    DMA_InitStructure.DMA_PeripheralBaseAddr = (u32)&BACKLIGHT_TIM_CVR;
    DMA_InitStructure.DMA_MemoryBaseAddr = memadr;
    DMA_InitStructure.DMA_DIR = DMA_DIR_PeripheralDST;
    DMA_InitStructure.DMA_BufferSize = 1;
    DMA_InitStructure.DMA_PeripheralInc = DMA_PeripheralInc_Disable;
    DMA_InitStructure.DMA_MemoryInc = DMA_MemoryInc_Disable;
    DMA_InitStructure.DMA_PeripheralDataSize = DMA_PeripheralDataSize_HalfWord;
    DMA_InitStructure.DMA_MemoryDataSize = DMA_MemoryDataSize_HalfWord;
    DMA_InitStructure.DMA_Mode = DMA_Mode_Circular;
    DMA_InitStructure.DMA_Priority = DMA_Priority_High;
    DMA_InitStructure.DMA_M2M = DMA_M2M_Disable;
    DMA_Init(BACKLIGHT_TIM_DMA_CHANNEL, &DMA_InitStructure);

    DMA_Cmd(BACKLIGHT_TIM_DMA_CHANNEL, ENABLE);
}
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
int main(void)
{
    uint8_t previous_matrix_state[N_COLS];
    key_report_t key_report;
    uint8_t previous_c = 200;

    memset(previous_matrix_state, 0, N_COLS);
    memset(&key_report, 0, sizeof(key_report_t));

    /* set all data and flags to 0 */
    memset(&state, 0, sizeof(addon_state_t));

    /* set the version number from git */
    char version_major[] = VERSION_MAJOR;
    char version_minor[] = VERSION_MINOR;
    char version_patch[] = VERSION_PATCH;
    state.data.version[0] = atoi(version_major) & 0xff;
    state.data.version[1] = atoi(version_minor) & 0xff;
    state.data.version[2] = atoi(version_patch) & 0xff;

    SystemInit();
#ifdef NVIC_PriorityGroup_2
    NVIC_PriorityGroupConfig(NVIC_PriorityGroup_2);
#else
    NVIC_PriorityGroupConfig(NVIC_PriorityGroup_1);
#endif
    SystemCoreClockUpdate();
    Delay_Init();

    /* makes sure that we can still flash using SWD */
    Delay_Ms(1000);

    /* initialize i2c */
    IIC_Init(I2C_SPEED, I2C_ADDRESS); // disables SWD

    PRINT("SystemClk: %u\r\n", (unsigned)SystemCoreClock);
    PRINT("ChipID: %08x\r\n", (unsigned)DBGMCU_GetCHIPID());

    /* configure the keyboard backlight PWM output using DMA */
    Backlight_PWM_Init(100, TIMER_FREQ, state.data.backlight);
    Backlight_PWM_DMA_Init((u32)&state.data.backlight);
    TIM_DMACmd(BACKLIGHT_TIM, TIM_DMA_Update, ENABLE);
    TIM_Cmd(BACKLIGHT_TIM, ENABLE);
    TIM_CtrlPWMOutputs(BACKLIGHT_TIM, ENABLE);

    /* Initialize GPIO for keyboard scan */
    KB_Scan_Init();
    // KB_Sleep_Wakeup_Cfg();

    /* Initialize timer for Keyboard and mouse scan timing */
    TIM3_Init(1, TIMER_FREQ); // every 10 ms

    /* Initialize USBFS interface to communicate with the host  */
    USB_init();

    boot_animation();

    /* set the keyboard backlight off */
    state.data.backlight = 0;

    /* UART output is enabled by default; can be disabled through I2C configuration */
    state.data.enable_uart_output = 1;
    state.flag_uart_enabled = 0;
    state.flag_config_changed = 1;

    while (1)
    {
        if (state.flag_button_scan_halfway && state.data.enable_int)
        {
            state.flag_button_scan_halfway = 0;
            // TODO: set interrupt pin low
        }

        if (state.flag_matrix_scan_done)
        {
            state.flag_matrix_scan_done = 0;

            if (memcmp(state.matrix_state, previous_matrix_state, N_COLS) != 0)
            {
                // matrix state has changed
                for (int c = 0; c < N_COLS; c++)
                {
                    if (state.matrix_state[c] != previous_matrix_state[c])
                    {
                        for (int r = 0; r < N_ROWS; r++)
                        {
                            uint8_t current_button_state = (state.matrix_state[c] & (1 << r)) & 0xff;
                            uint8_t previous_button_state = (previous_matrix_state[c] & (1 << r)) & 0xff;

                            if (current_button_state != previous_button_state)
                            {
                                uint8_t keycode;
                                uint8_t is_modifier = get_keycode(c, r, &keycode);
                                if (is_modifier != 2)
                                {
                                    determine_hid_report(keycode, is_modifier, current_button_state, &key_report);
                                }
                            }
                        }
                    }
                }

                /* Copy the keyboard data to the buffer of endpoint 1 and set the data uploading flag */
                memcpy(previous_matrix_state, state.matrix_state, N_COLS);

                /* handle special FN triggers */
                handle_fn(&key_report, &state.data.key_report);

                /* the key report is ready to be fetched through I2C, so let's set the interrupt */
                if (state.data.enable_int)
                {
                    // TODO: set the UART TX to high
                    PRINT("TODO: set the output pin\r\n");
                }
                else if (state.flag_uart_enabled)
                {
#if (DEBUG)
                    PRINT("Reporting HID through UART:\r\n");
                    for (int i = 0; i < sizeof(key_report_t); i++)
                    {
                        PRINT("0x%02x ", state.raw_data[RESULT_KB_OFFSET + i]);
                    }
                    PRINT("\r\n");
#else
                    for (int i = 0; i < sizeof(key_report_t); i++)
                    {
                        while (USART_GetFlagStatus(UART, USART_FLAG_TC) == RESET)
                            ;
                        USART_SendData(UART, state.raw_data[RESULT_KB_OFFSET + i]);
                    }
#endif
                }

                USB_write(&state.raw_data[RESULT_KB_OFFSET], sizeof(key_report_t));
            }
        }

        /* uart receive a backlight brightness */
        if (USART_GetFlagStatus(UART, USART_FLAG_RXNE) != RESET)
        {
            uint8_t c = USART_ReceiveData(UART);
            /* if we previously received a valid value, do a checksum check */
            if (previous_c <= 100 && (c == (previous_c ^ 0xFF)))
            {
                PRINT("setting backlight through UART: %d\r\n", previous_c);
                state.data.backlight = (uint16_t)previous_c;
                previous_c = 200; /* set the previous value to an invalid value */
            }
            else
            {
                previous_c = c;
            }
        }

        /* I2C master wrote a new value to the outputs register: apply it now.
         * Also handles the reboot-to-bootloader command if that bit is set.
         */
        if (state.flag_config_changed)
        {
            state.flag_config_changed = 0;
            if (state.data.reboot)
            {
                PRINT("Reboot to bootloader trigger\r\n");
                Delay_Ms(100);
                SystemReset_StartMode(Start_Mode_BOOT);
                NVIC_SystemReset();
            }
            if (state.data.remap)
            {
                PRINT("Remap SWD trigger\r\n");
                Delay_Ms(100);
                /* disable I2C interrupts */
                I2C_ITConfig(I2C1, I2C_IT_EVT | I2C_IT_ERR | I2C_IT_BUF, DISABLE);

                /* disable I2C1 */
                I2C_Cmd(I2C1, DISABLE);

                /* Re-enable DIO (SWD) interface on these pins */
                GPIO_PinRemapConfig(GPIO_Remap_SWJ_Disable, DISABLE);
            }
            if (state.data.enable_uart_output)
            {
                USART_Output_Init(UART_BAUDRATE);
            }
            else
            {
                USART_Output_DeInit();
            }
        }
    }
}

/* interrupt handlers */
void NMI_Handler(void) __attribute__((interrupt("WCH-Interrupt-fast")));
void NMI_Handler(void)
{
    PRINT("NMI_Handler\r\n");
}

void HardFault_Handler(void) __attribute__((interrupt("WCH-Interrupt-fast")));
void HardFault_Handler(void)
{
    PRINT("HARDFAULT\r\n");
    while (1)
    {
    }
}

void I2C1_IRQHandler(void) __attribute__((interrupt("WCH-Interrupt-fast")));
void I2C1_IRQHandler(void)
{
    PRINT("I2C1_IRQHandler\r\n");
}

// Interrupt Service Routine for I2C1 Event
void I2C1_EV_IRQHandler(void) __attribute__((interrupt));
void I2C1_EV_IRQHandler(void)
{
    i2c_slave_process();
}

/* I2C1 Error — clear whichever error flag fired so the bus is not blocked. */
void I2C1_ER_IRQHandler(void) __attribute__((interrupt));
void I2C1_ER_IRQHandler(void)
{
    uint16_t STAR1 = I2C1->STAR1;
    if (STAR1 & I2C_STAR1_BERR) I2C1->STAR1 &= ~I2C_STAR1_BERR;
    if (STAR1 & I2C_STAR1_ARLO) I2C1->STAR1 &= ~I2C_STAR1_ARLO;
    if (STAR1 & I2C_STAR1_AF) I2C1->STAR1 &= ~I2C_STAR1_AF;
}

/*********************************************************************
 * @fn      TIM3_IRQHandler
 *
 * @brief   This function handles TIM3 global interrupt request.
 *
 * @return  none
 */
void TIM3_IRQHandler(void) __attribute__((interrupt("WCH-Interrupt-fast")));
void TIM3_IRQHandler(void)
{
    if (TIM_GetITStatus(TIM3, TIM_IT_Update) != RESET)
    {
        /* Clear interrupt flag */
        TIM_ClearITPendingBit(TIM3, TIM_IT_Update);

        /* Handle keyboard scan */
        KB_Scan();
    }
}

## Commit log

2026-06-02 hardware files added
    [Bill of Materials-Fri3d_2026_Keeb_00(Default).xls, Bill of Materials-Fri3d_2026_Keeb_01(Default).xls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]
2026-08-10 apply i2c write fix from badge_expander
    [main.c]
2026-08-17 allow disabling the UART output over i2c
